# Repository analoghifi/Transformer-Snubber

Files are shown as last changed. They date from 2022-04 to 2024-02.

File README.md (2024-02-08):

# Transformer-Snubber
very effective transformer secondary snubber - without "Rectifier snubbing", the widespread (inaccurate) use of capacitors across the rectifier diodes  

----

Please read the doc:  
"<a href="docs/Quasimodo_jig_revA.pdf">Simple, No-Math Transformer Snubber using “Quasimodo” Test Jig.pdf</a>" by <a href="https://linearaudio.net/authors/436">Mark Johnson</a>  
  
That's what this repo is about:  
Construction of a test jig to determine the correct values for a CRC\* snubber, which fits individually to the measured transformer type, so that no overshoot (=ringing / noise) occurs.  
(see as well this <a href="https://www.diyaudio.com/community/threads/simple-no-math-transformer-snubber-using-quasimodo-test-jig.243100/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">forum thread</a> on <a href="https://www.diyaudio.com/community/forums/-/list">diyaudio.com</a> forums)   
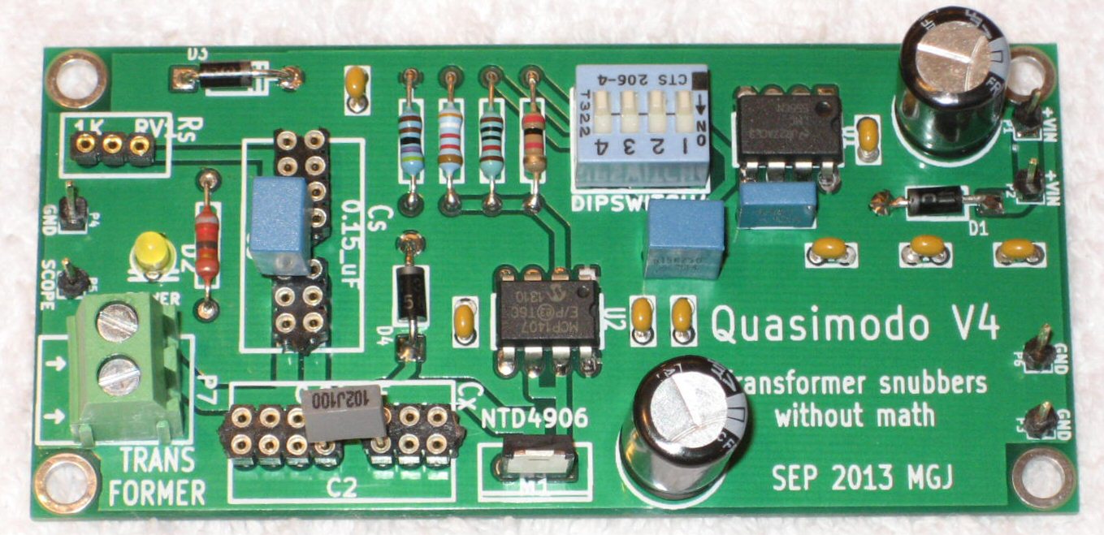
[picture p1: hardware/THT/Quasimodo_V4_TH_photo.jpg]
  

----

\*here we use a three element "CRC" snubber on the secondary side of the transformer  
and the exact values for Cx, Rs and Cs (individually for each transformer type) are determined with our "Quasimodo" test jig and an oscilloscope.  
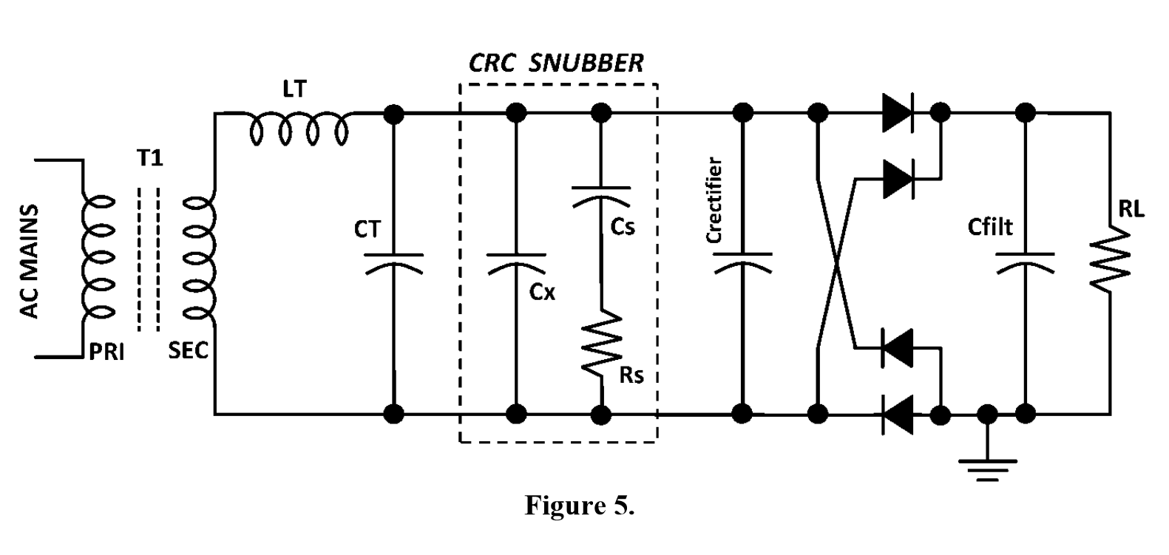
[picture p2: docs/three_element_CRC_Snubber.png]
  
  
----

see as well this excellent article by <a href="https://linearaudio.net/authors/436">Mark Johnson</a> about the basics and backgrounds of this topic   
"<a href="docs/related/Soft Recovery Diodes Lower Transformer Ringing by 10-20X.pdf">Soft Recovery Diodes Lower Transformer Ringing by 10-20X.pdf</a>"

----

here is also a mathematical approach from TI   
(but for switched-mode power supplies. However, it can also be used for 50/60 Hz applications)  
https://e2e.ti.com/blogs_/b/powerhouse/posts/calculate-an-r-c-snubber-in-seven-steps  
Backup here: <a href="docs/related/Power Tips Calculate an R-C snubber in seven steps.pdf">docs/related/Power Tips Calculate an R-C snubber in seven steps.pdf</a>
  
----  
### Kicad projects in this repo:  
* [quasimodo THT](https://github.com/analoghifi/Transformer-Snubber/tree/main/hardware/KiCad/THT/original) | state: initial release v1.01 | like the original, 2-layer, THT
* [quasimodo SMD](https://github.com/analoghifi/Transformer-Snubber/tree/main/hardware/KiCad/SMD/original) | state: coming soon... | like the original, 2-layer, SMD

----

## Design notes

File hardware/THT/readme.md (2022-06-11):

for this THT version see my newly recreated KiCad6.x project here: <a href="https://github.com/analoghifi/Transformer-Snubber/tree/main/hardware/KiCad/THT/original">hardware/KiCad/THT/original</a>

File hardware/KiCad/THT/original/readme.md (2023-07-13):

these are KiCad 6.x projects  
see how to get the proper 3D-Models from here: https://github.com/analoghifi/KiCad-3D-Models

use kicanvas.org to see this KiCad-Project in your browser:  
https://kicanvas.org/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

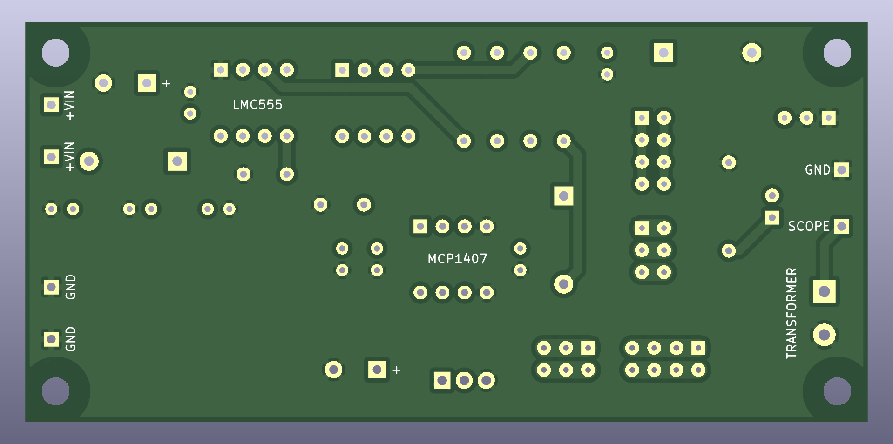
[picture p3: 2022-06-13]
hardware/KiCad/THT/original/quasimodo_tht_orig__bottom.png

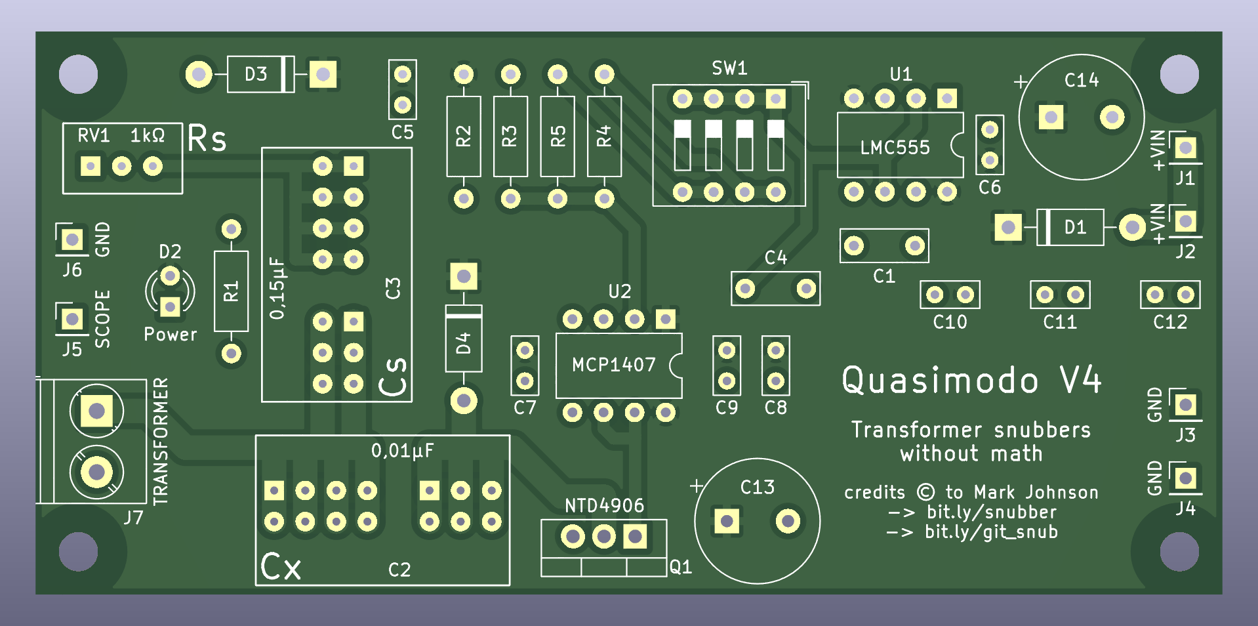
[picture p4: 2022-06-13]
hardware/KiCad/THT/original/quasimodo_tht_orig__top2.png

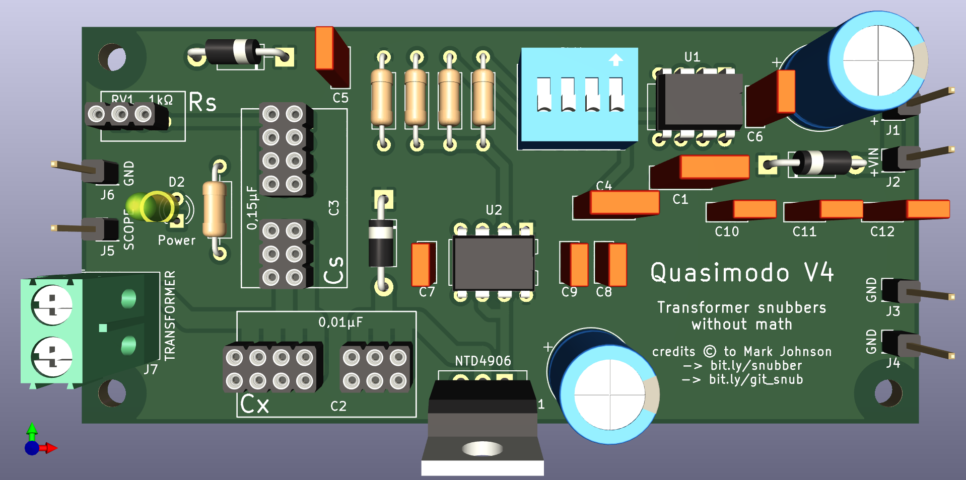
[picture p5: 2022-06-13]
hardware/KiCad/THT/original/quasimodo_tht_orig__top1.png

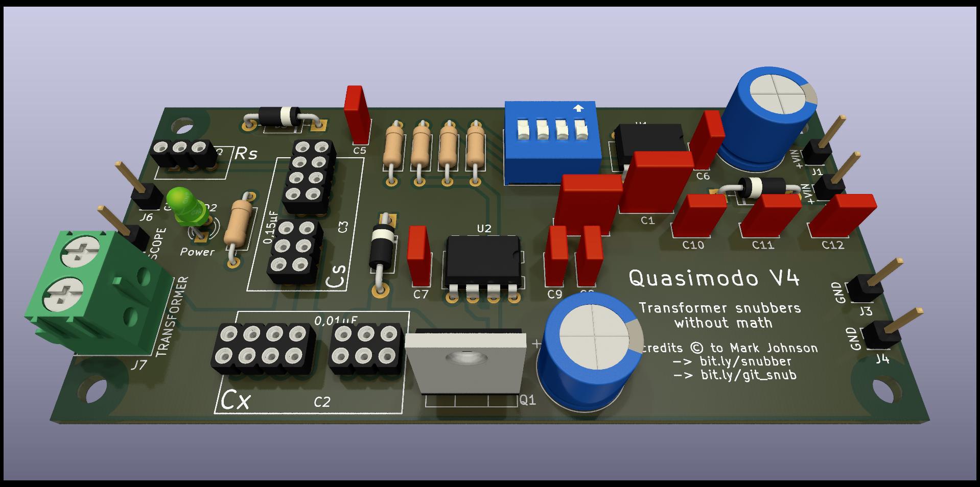
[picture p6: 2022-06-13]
hardware/KiCad/THT/original/quasimodo_tht_orig__3D.jpg

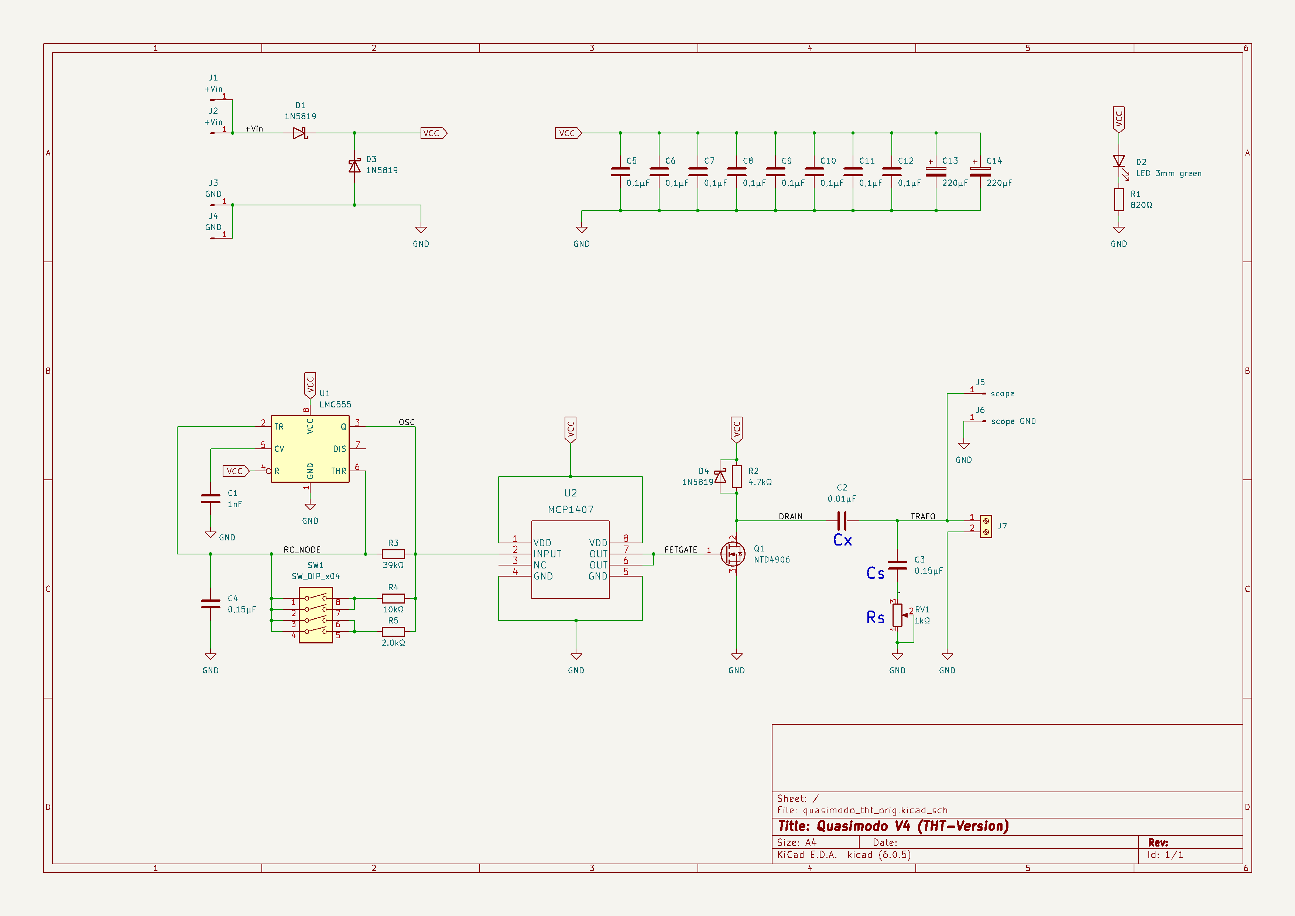
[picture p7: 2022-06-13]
hardware/KiCad/THT/original/quasimodo_tht_orig.sch.png

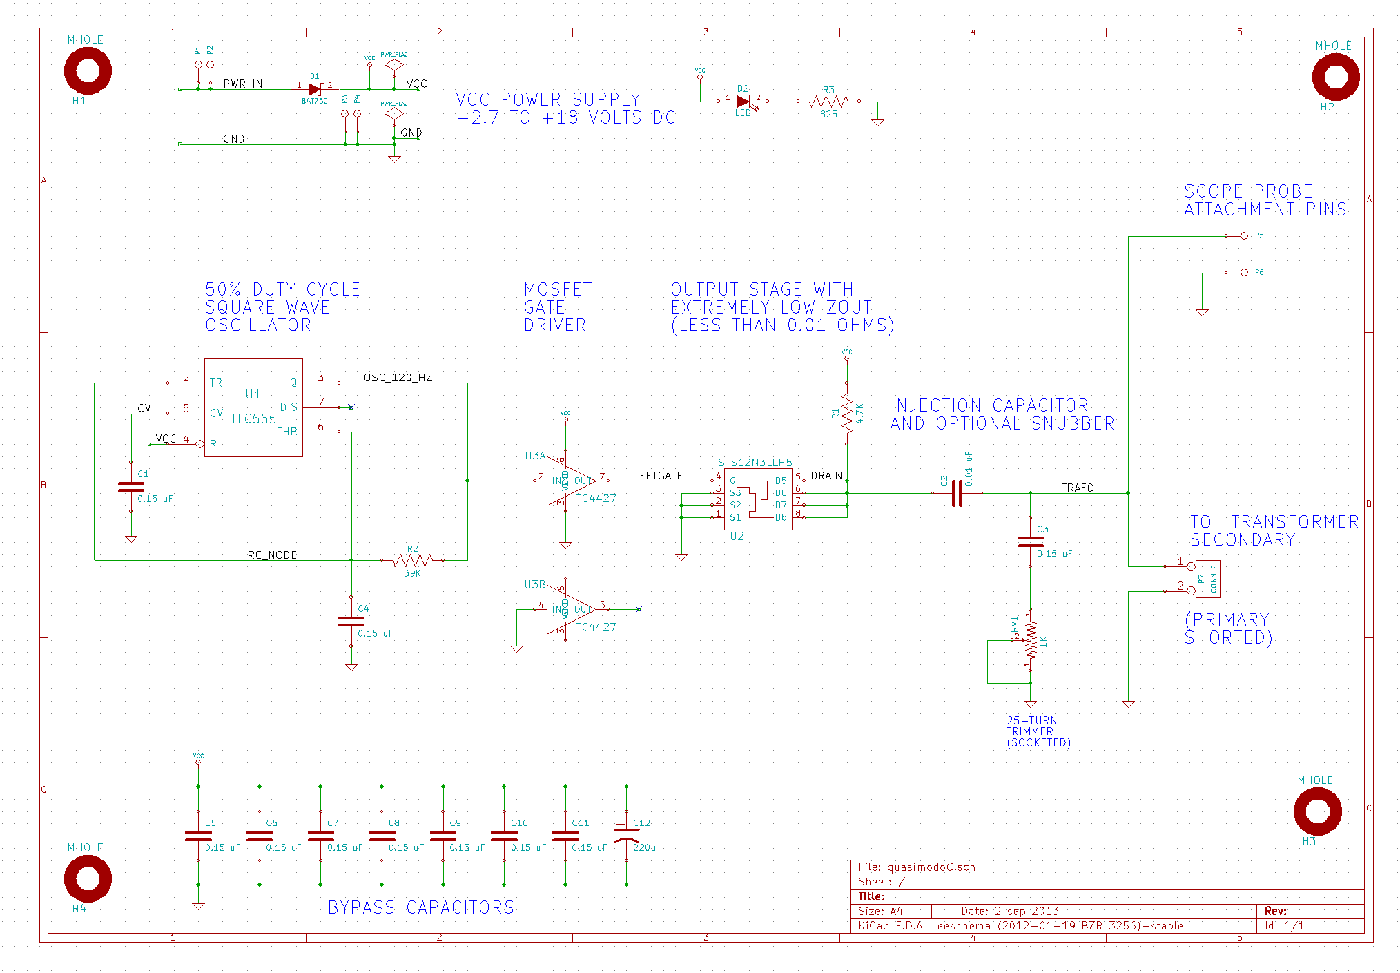
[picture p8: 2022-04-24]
hardware/SMD/Quasimodo_SMD_schematic.png

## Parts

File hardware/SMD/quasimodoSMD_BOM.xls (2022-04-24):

Description | Value | Rating | Mfr | pkg | qty | sch reference# | substitute #1 | substitute #2
removable cap | 0.01u | >30V |  | thru hole | 1 | C2
ceramic cap | 0.15u | >30V | Samsung | 1206 | 10 | C1; C3-C11
25 turn trimpot | 1K |  | Murata | inline-3 | 1 | RV1 | Bourns 3296W | Murata PV36W
electrolytic cap | 220u | 35V | Panasonic | 8.3 x 8.3 mm | 1 | C12 | DK PCE3419 | DK 565-2478-1
resistor | 39K | 1/4 watt |  | 1206 | 1 | R2
resistor | 4.7K | 1/4 watt |  | 1206 | 1 | R1
resistor | 825 | 1/2 watt |  | 1206 | 1 | R3
schottky diode | BAT750 |  | Diodes Inc | SOT-23-3 | 1 | D1 | ZLLS1000 | BAT400D
header, breakaway | 1 pin |  | TE Connec |  | 6 | P1-P6 | DK A26509-40-ND | DK ED90324-ND
terminal block | 2 pin @ 0.2" |  | On Shore |  | 1 | P7 | DK ED2609-ND | DK ED2902-ND
LED | APT3216 |  | Kingbright | 1206 | 1 | D2 | any 1206 LED | any 3216 LED
Nch MOSFET | STS12N3LLH5 |  | ST Micro | 8-SOIC | 1 | U2 | IRF8721 | IRF8714
gate driver IC | TC4427ACOA |  | Microchip | 8-SOIC | 1 | U3 | TC4426 | TC4424
timer/osc IC | TLC555CDR |  | TI | 8-SOIC | 1 | U1 | LMC555CMX
solder tail socket | 3 x 2 @ 0.1" |  | Preci-Dip | thru hole | 1 | for C2 | DK 1212-1157-ND
solder tail socket | 4 x 2 @ 0.1" |  | Preci-Dip | thru hole | 1 | for C2 | DK 1212-1157-ND
solder tail socket | 3 x 1 @ 0.1" |  | Preci-Dip | thru hole | 1 | for RV1 | DK 1212-1114-ND
PCBoard | 5cm x 5cm |  | Seeed | SMD | 1
note: "DK" means Digi-Key

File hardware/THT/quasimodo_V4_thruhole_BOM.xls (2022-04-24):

Description | Value | Rating | Mfr | pkg | qty | sch reference# | substitute #1 | substitute #2
removable cap | 0.01u | >30V | EPCOS | thru hole | 1 | C2
removable cap | 0.15u | >30V | EPCOS | thru hole | 1 | C3
capacitor | 1n | >30V |  | 0.2" lead spacing | 1 | C1
ceramic cap X7R | 0.1u | >30V |  | 0.1" lead spacing | 8 | C5-12
film cap | 0.15u | >30V |  | 0.2" lead spacing | 1 | C4
electrolytic cap | 220u | >30V | Panasonic | LS=5mm, Dia=8mm | 2 | C13-14
25 turn trimpot | 1K |  | Murata | inline, LS= 0.1" | 1 | RV1 | Murata PV36W | Bourns 3296W
resistor | 820R | 1W | Yaego | diameter < 3.3 mm | 1 | R1 | DK PPC820W
resistor | 4.7K | 0.25W |  | axial | 1 | R2
resistor | 39K | 0.25W |  | axial | 1 | R3
resistor | 10K | 0.25W |  | axial | 1 | R4
resistor | 2.0K | 0.25W |  | axial | 1 | R5
schottky diode | 1N5819 |  | Vishay | DO41 | 3 | D1;D3;D4 | SB140 | 11DQ04
LED | WP710 |  | Kingbright | T-1, 3mm | 1 | D2 | any T1 LED
timer/osc | LMC555CN |  | TI | DIP-8 | 1 | U1 | TLC555
FET gate driver | MCP1407-E/P |  | Microchip | DIP-8 | 1 | U2 | TC4420 | TC4429
power MOSFET | NTD4906N |  | ON Semi | IPAK or TO220 | 1 | M1 | IRLB8748 | IRLU8726
DIPswitch 4pos | 206-4ST |  | CTS | DIP-8 | 1 | U3 | DK 450-1781 | DK 450-1364
header, breakaway | 1 pin |  | TE Connec | 0.1" sp, breakaway | 6 | P1-6 | DK A26509-40-ND | DK ED90324-ND
terminal block | 2 pin @ 0.2" |  | On Shore | wire to board | 1 | P7 | DK ED2609-ND | DK ED2902-ND
solder tail socket | 3 x 2 @ 0.1" |  | Preci-Dip | thru hole | 2 | for C2&C3 | DK 1212-1157-ND
solder tail socket | 4 x 2 @ 0.1" |  | Preci-Dip | thru hole | 2 | for C2&C3 | DK 1212-1157-ND
solder tail socket | 3 x 1 @ 0.1" |  | Preci-Dip | thru hole | 1 | for RV1 | DK 1212-1114-ND
PCBoard | 5cm x 10cm |  | Seeed | thru hole | 1
note: "DK" means Digi-Key

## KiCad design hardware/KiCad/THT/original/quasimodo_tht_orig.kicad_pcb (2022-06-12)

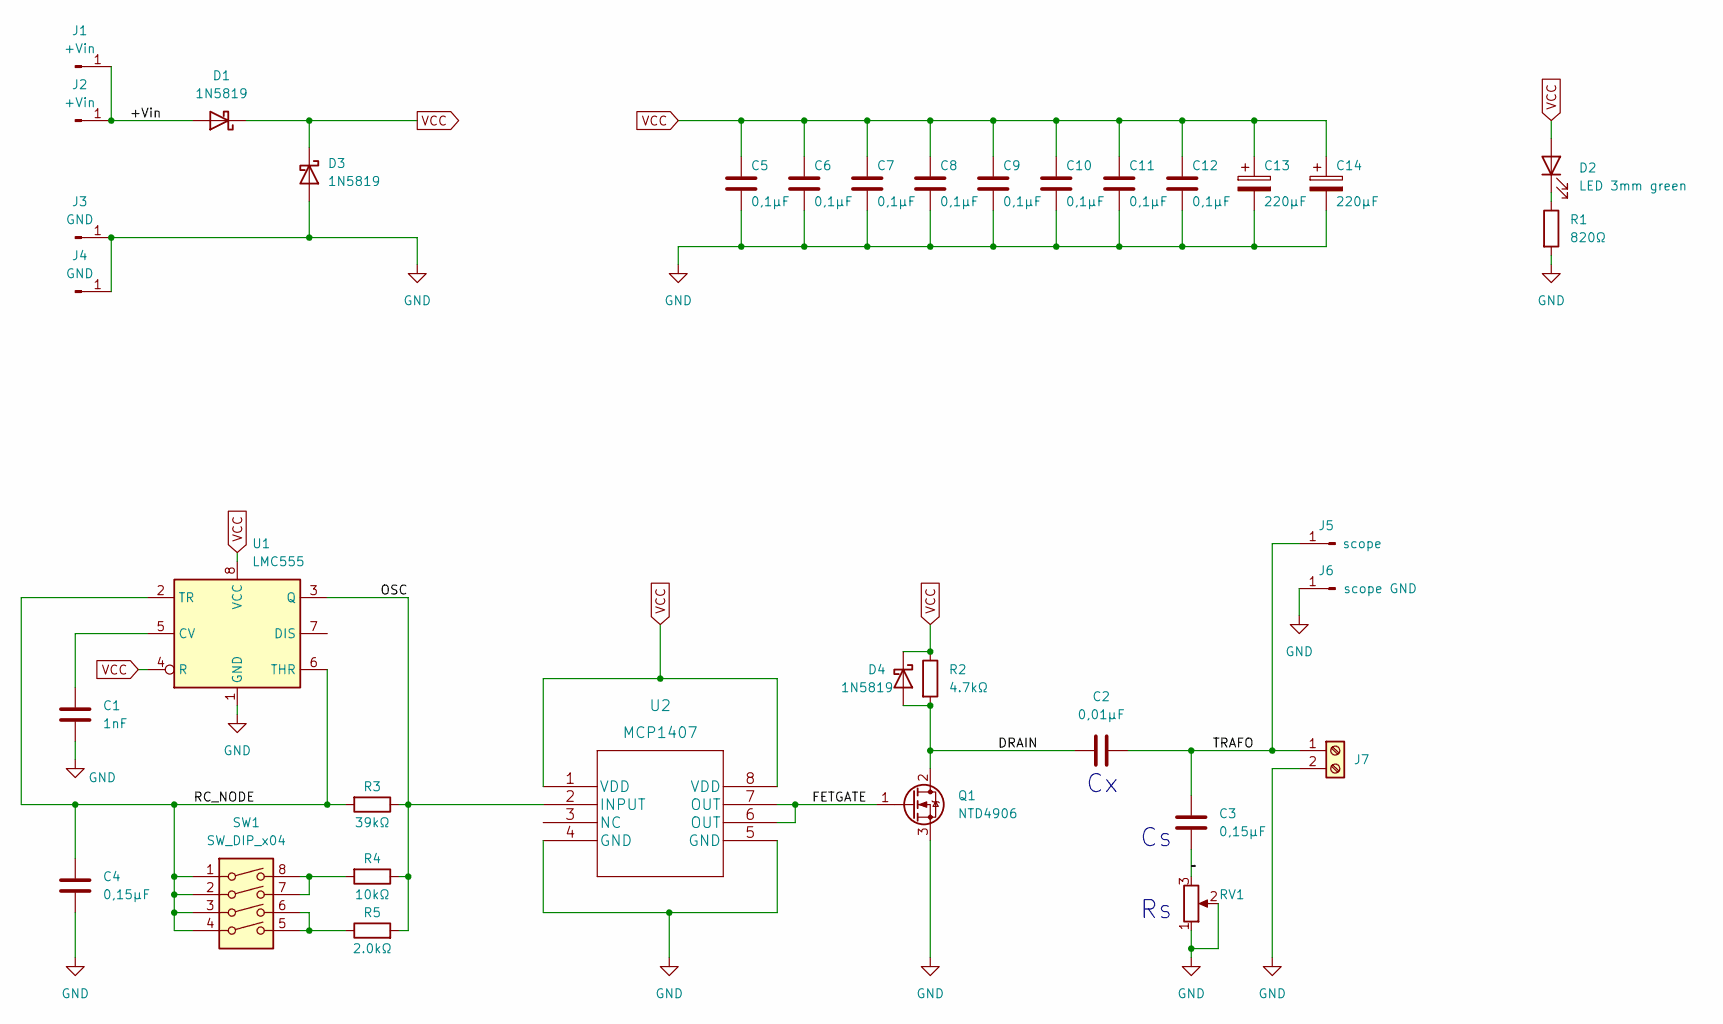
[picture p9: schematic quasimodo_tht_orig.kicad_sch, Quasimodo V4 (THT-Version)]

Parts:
C1: 1nF; C_Rect_L7.0mm_W2.5mm_P5.00mm
C2: 0,01µF
C3: 0,15µF
C4: 0,15µF; C_Rect_L7.0mm_W2.5mm_P5.00mm
C5, C6, C7, C8, C9, C10, C11, C12: 0,1µF; C_Rect_L4.6mm_W2.0mm_P2.50mm_MKS02_FKP02
C13, C14: 220µF; CP_Radial_D10.0mm_P5.00mm_medium_silk
D1, D3, D4: 1N5819; D_DO-41_SOD81_P10.16mm_Horizontal
D2: LED 3mm green; LED_D3.0mm
J1, J2: +Vin; PinHeader_1x01_P2.54mm_Vertical
J3, J4: GND; PinHeader_1x01_P2.54mm_Vertical
J5: scope; PinHeader_1x01_P2.54mm_Vertical
J6: scope GND; PinHeader_1x01_P2.54mm_Vertical
J7: Screw_Terminal_01x02; TerminalBlock_Phoenix_PT-1,5-2-5.0-H_1x02_P5.00mm_Horizontal
Q1: NTD4906; TO-220-3_Vertical
R1: 820Ω; R_Axial_DIN0207_L6.3mm_D2.5mm_P10.16mm_Horizontal
R2: 4.7kΩ; R_Axial_DIN0207_L6.3mm_D2.5mm_P10.16mm_Horizontal
R3: 39kΩ; R_Axial_DIN0207_L6.3mm_D2.5mm_P10.16mm_Horizontal
R4: 10kΩ; R_Axial_DIN0207_L6.3mm_D2.5mm_P10.16mm_Horizontal
R5: 2.0kΩ; R_Axial_DIN0207_L6.3mm_D2.5mm_P10.16mm_Horizontal
RV1: Potentiometer_Bourns_3296W_Vertical
SW1: SW_DIP_x04; SW_DIP_SPSTx04_Slide_9.78x12.34mm_W7.62mm_P2.54mm
U1: LMC555; DIP-8_W7.62mm
U2: MCP1407; DIP-8_W7.62mm

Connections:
/+Vin: D1.2 (A), J1.1, J2.1
/DRAIN: C2.1, D4.2 (A), Q1.2 (D), R2.2; also elsewhere on the board
/FETGATE: Q1.1 (G), U2.6 (OUT), U2.7 (OUT)
/OSC: R3.1, R4.1, R5.2, U1.3 (Q), U2.2 (INPUT)
/RC_NODE: C4.1, R3.2, SW1.1, SW1.2, SW1.3, SW1.4, U1.2 (TR), U1.6 (THR)
/TRAFO: C2.2, C3.1, J5.1, J7.1; also elsewhere on the board
GND: C1.2, C4.2, C5.2, C6.2, C7.2, C8.2, C9.2, C10.2, C11.2, C12.2, C13.2, C14.2, D3.2 (A), J3.1, J4.1, J6.1, J7.2, Q1.3 (S), R1.2, RV1.1, RV1.2, U1.1 (GND), U2.4 (GND), U2.5 (GND); also elsewhere on the board
unnamed: C1.1, U1.5 (CV)
unnamed: C3.2, RV1.3
unnamed: D2.1 (K), R1.1
unnamed: R4.2, SW1.7, SW1.8
unnamed: R5.1, SW1.5, SW1.6
VCC: C5.1, C6.1, C7.1, C8.1, C9.1, C10.1, C11.1, C12.1, C13.1, C14.1, D1.1 (K), D2.2 (A), D3.1 (K), D4.1 (K), R2.1, U1.4 (R), U1.8 (VCC), U2.1 (VDD), U2.8 (VDD)

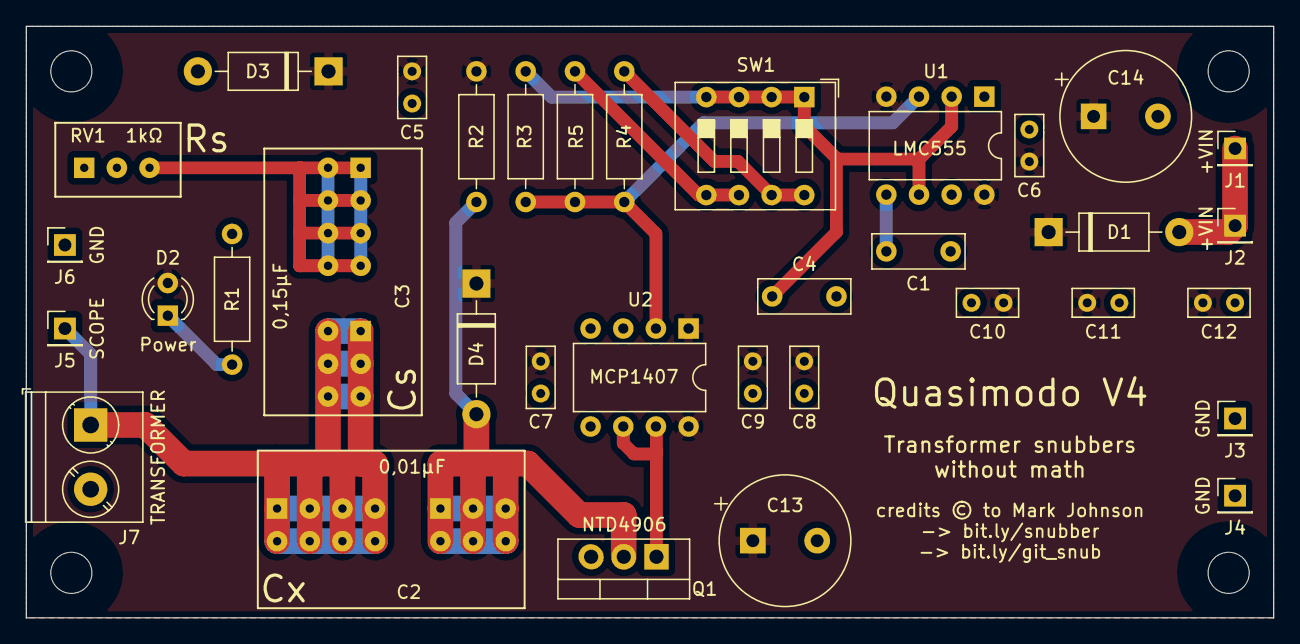
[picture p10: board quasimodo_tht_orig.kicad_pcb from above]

Board: 2 copper layers, 97.0 x 46.0 mm, 37 parts (0 on the bottom side), 13 nets.

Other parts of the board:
Cs_1: Preci-Dip_2x03_P2.54mm_Vertical_no_silk
Cs_2: Preci-Dip_2x04_P2.54mm_Vertical_no_silk
Cx_1: Preci-Dip_2x03_P2.54mm_Vertical_no_silk
Cx_2: Preci-Dip_2x04_P2.54mm_Vertical_no_silk
Rs: Preci-Dip_1x03_P2.54mm_Vertical_no_silk

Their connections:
/DRAIN: Cx_1.1, Cx_1.2, Cx_1.3, Cx_1.4, Cx_1.5, Cx_1.6; also elsewhere on the board
/TRAFO: Cs_1.1, Cs_1.2, Cs_1.3, Cs_1.4, Cs_1.5, Cs_1.6, Cx_2.1, Cx_2.2, Cx_2.3, Cx_2.4, Cx_2.5, Cx_2.6, Cx_2.7, Cx_2.8; also elsewhere on the board
GND: Rs.1, Rs.2; also elsewhere on the board
Rs_Cs: Cs_2.1, Cs_2.2, Cs_2.3, Cs_2.4, Cs_2.5, Cs_2.6, Cs_2.7, Cs_2.8, Rs.3

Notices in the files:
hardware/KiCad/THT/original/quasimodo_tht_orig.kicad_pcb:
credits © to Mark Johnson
